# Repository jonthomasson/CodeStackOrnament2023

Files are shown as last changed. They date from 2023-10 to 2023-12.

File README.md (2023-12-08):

# CodeStack Team C 2023 Christmas Ornament Project

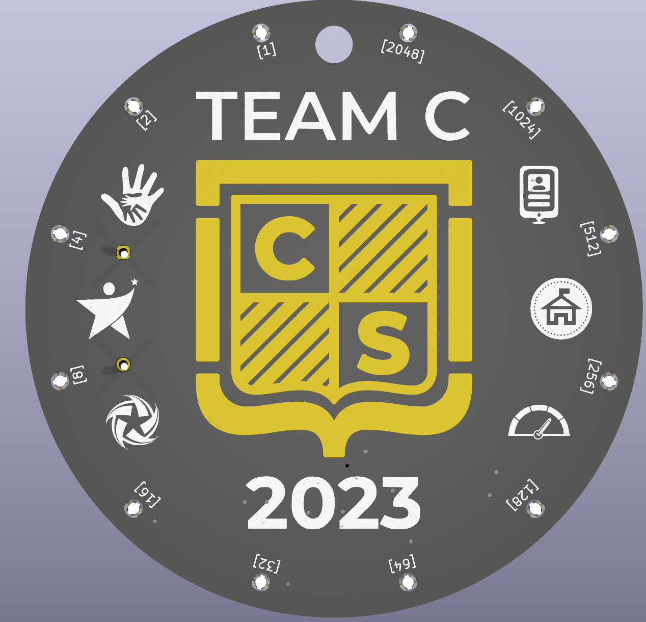
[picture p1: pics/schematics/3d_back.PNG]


## Overview

Welcome to the CodeStack Team C Christmas Ornament project! This isn't just any holiday decoration; it's a geeky masterpiece designed by developers for developers. Embodying the spirit of CodeStack, this unique ornament is a playful blend of electronics and a bit of geek culture, perfect for those who appreciate the quirks of digital logic and binary systems, which at its core are the systems which run our code!

### Circuit Description

Our circuit is centered around the 555 timer IC, configured in astable mode to generate a 4Hz timing signal, which feeds into a CD74HC4040 binary counter. The output from this binary counter powers 12 LEDs arranged around the PCB in a binary sequence.

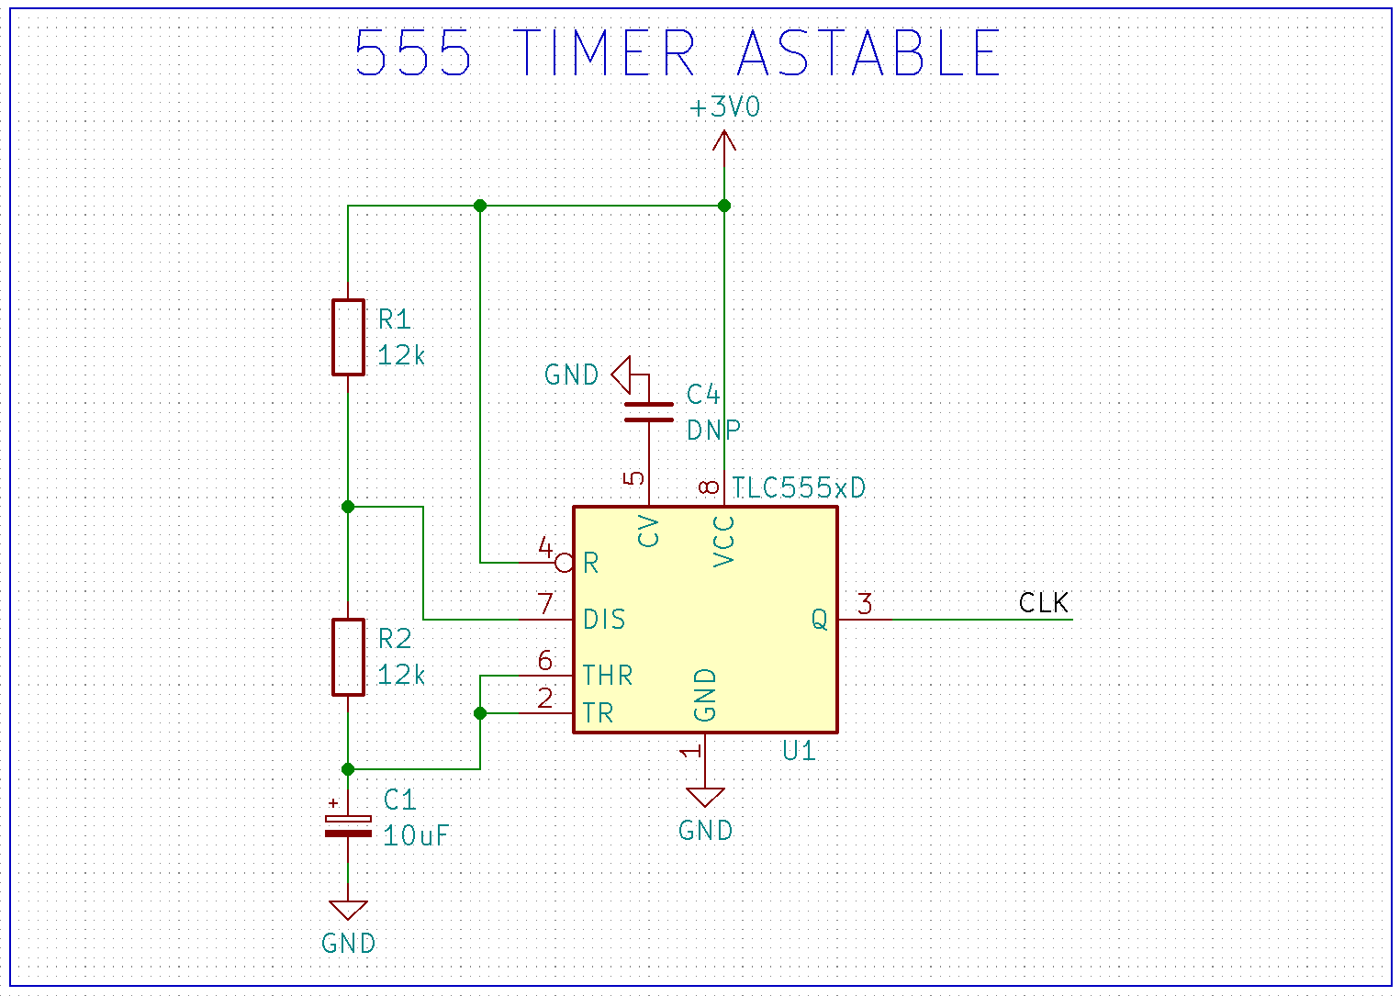
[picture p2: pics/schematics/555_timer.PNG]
555 Timer Schematic


#### Binary Counter and LED Display

At the core of our ornament is the CD74HC4040 binary counter. Unlike traditional LED displays, this counter follows a binary sequence, lighting up LEDs in a pattern that reflects binary counting principles.

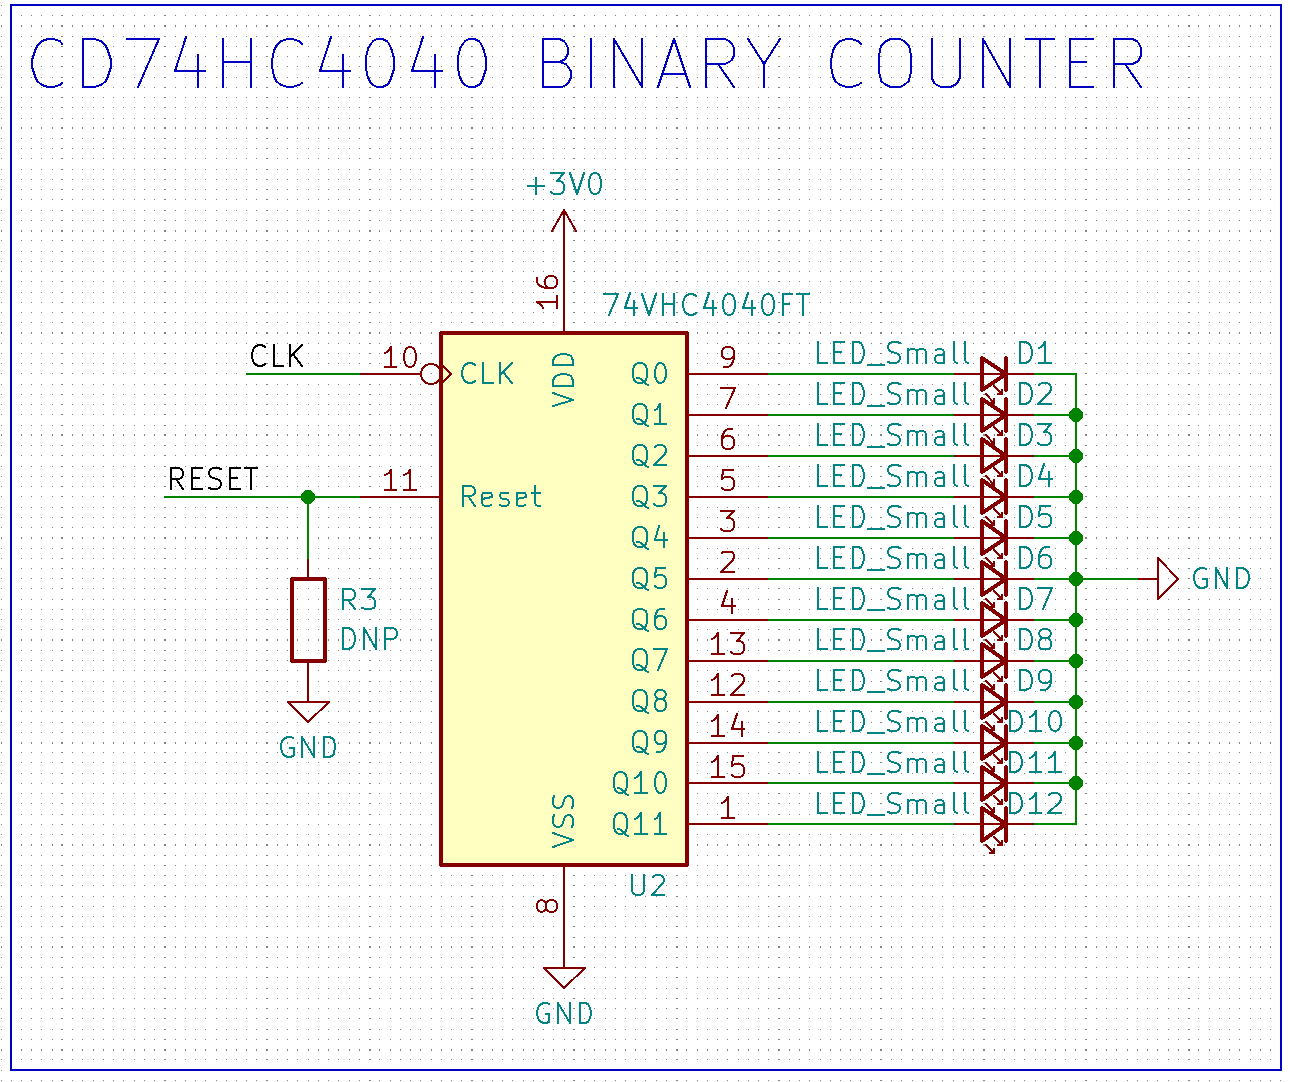
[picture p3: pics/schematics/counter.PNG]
Binary Counter Schematic


#### Reset Circuit

We've included a reset circuit using the TPS3840PH for a consistent experience. This setup ensures that the binary counter starts at zero every time the ornament is powered up. A manual reset button is also provided for added user control.

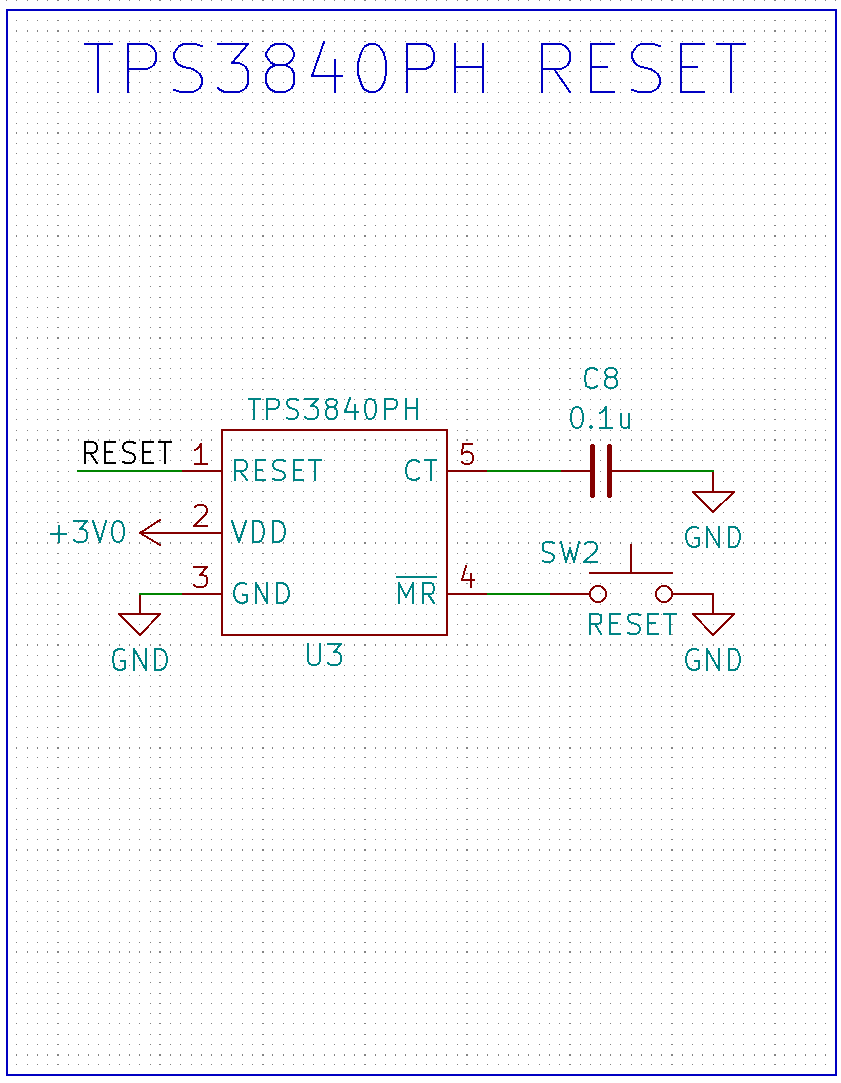
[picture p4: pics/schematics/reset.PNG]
Reset Circuit Schematic


## Embracing the Geekiness

This ornament is a nod to our geeky nature at CodeStack. It's designed to intrigue and amuse, combining fundamental electronics with a bit of developer humor. It's more than just a festive decoration; it's a representation of our love for coding, circuitry, and all things geeky.

## Binary Counting Explained

This ornament is a hands-on lesson in binary counting. The binary counter ranges from 0 to 4096, with each LED representing a binary power:

- 1, 2, 4, 8, 16, 32, 64, 128, 256, 512, 1024, and 2048.

As the counter advances, the corresponding LEDs light up. To find the current count, simply add the values of all illuminated LEDs. It's a delightful way to visualize how binary numbers work! Below is a representation of how the process of counting in binary works:

Binary Counting
## A Festive Joke

At first glance, it might just seem like an oddly blinking LED ornament. But in true CodeStack fashion, there's more than meets the eye. It's a playful demonstration of binary counting, making it not just a decoration, but a conversation piece about digital electronics and our geeky passions.

## Conclusion

Embrace your inner geek! This project aims to be a testament to our love for technology, coding, and a bit of festive fun. Enjoy this unique blend of holiday cheer and geek culture!

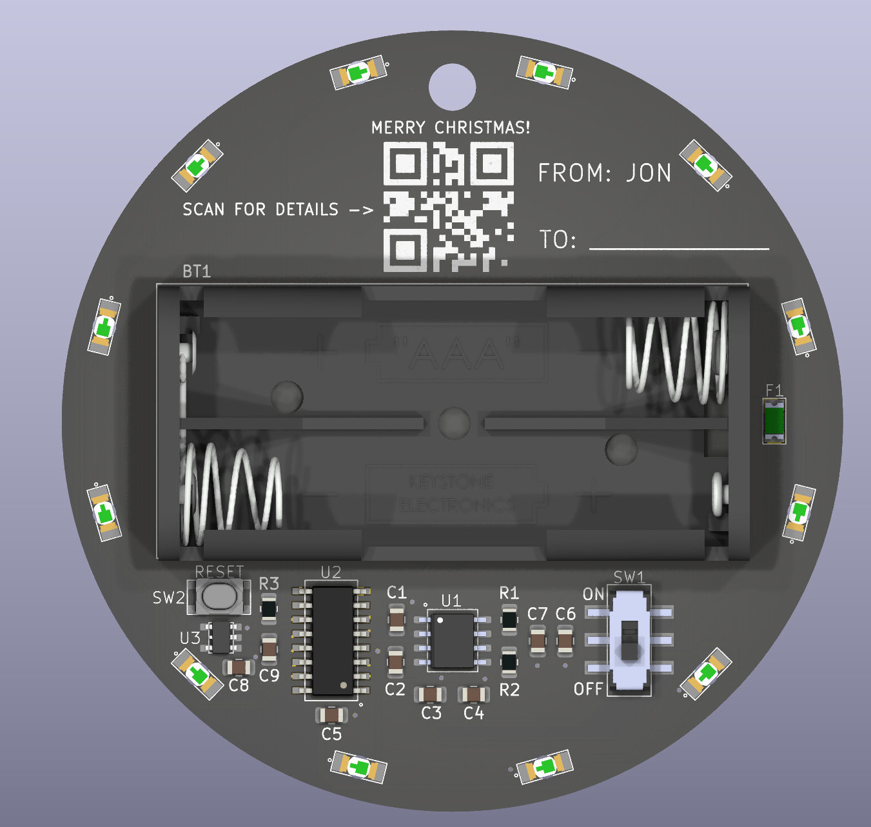
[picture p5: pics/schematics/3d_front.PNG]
Ornament Picture Front

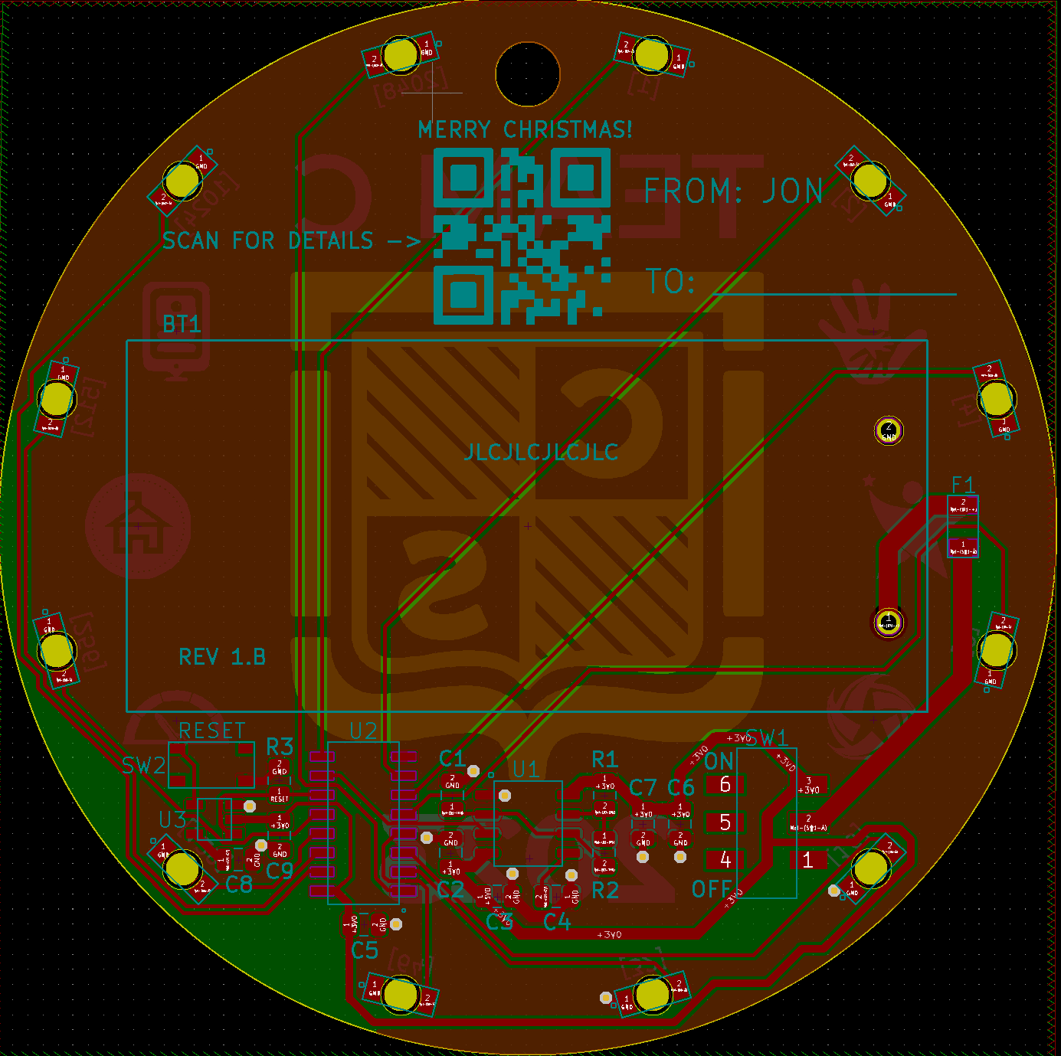
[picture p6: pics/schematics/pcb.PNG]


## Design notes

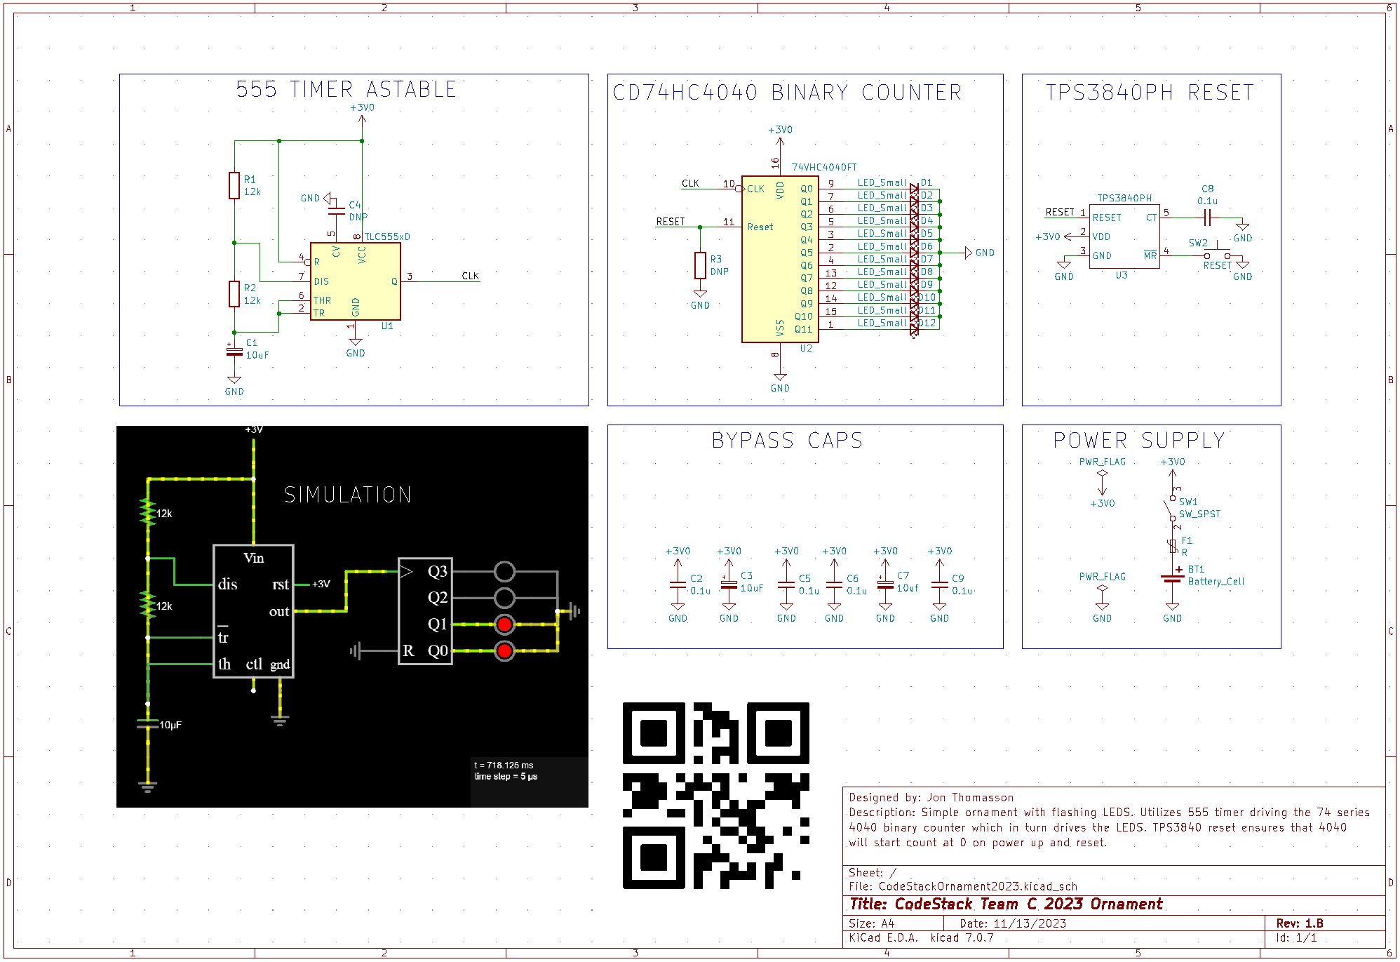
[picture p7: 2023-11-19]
pics/schematic.PNG

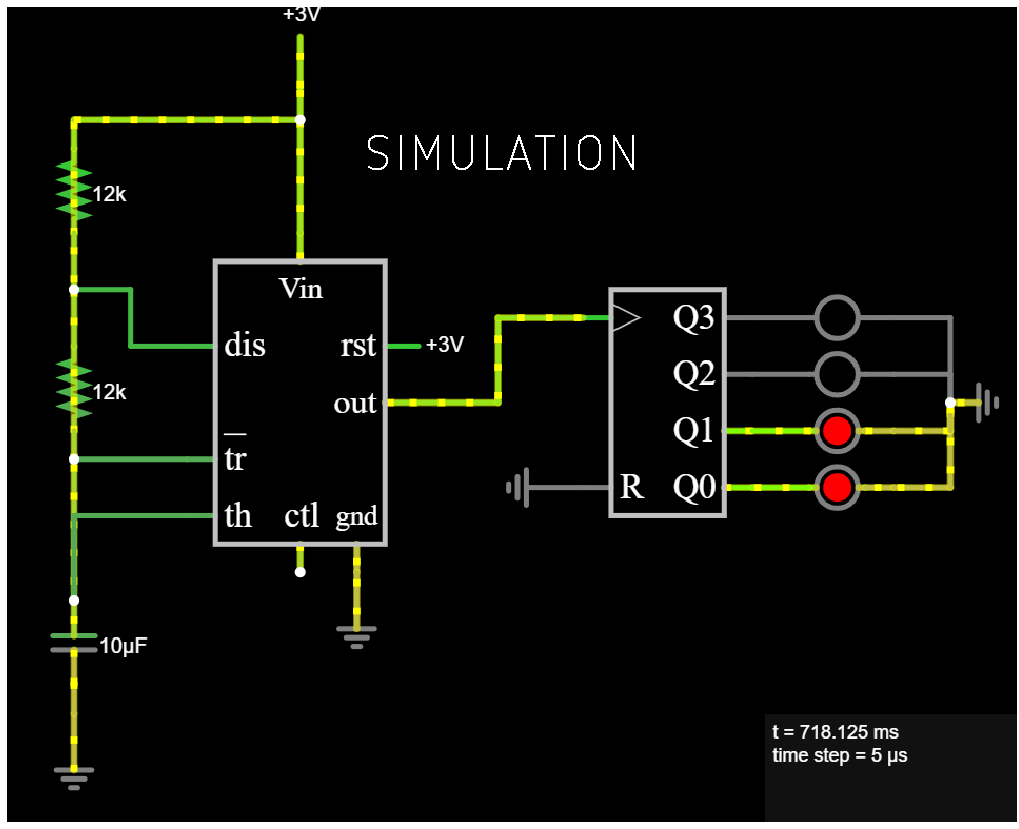
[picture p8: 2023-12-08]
pics/schematics/simulation.PNG

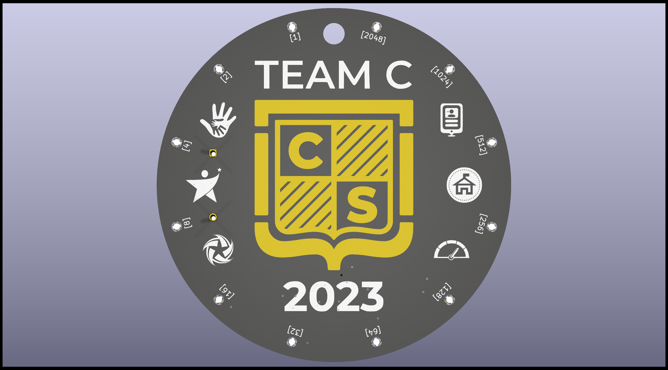
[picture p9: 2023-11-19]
pics/board-front-3d.png

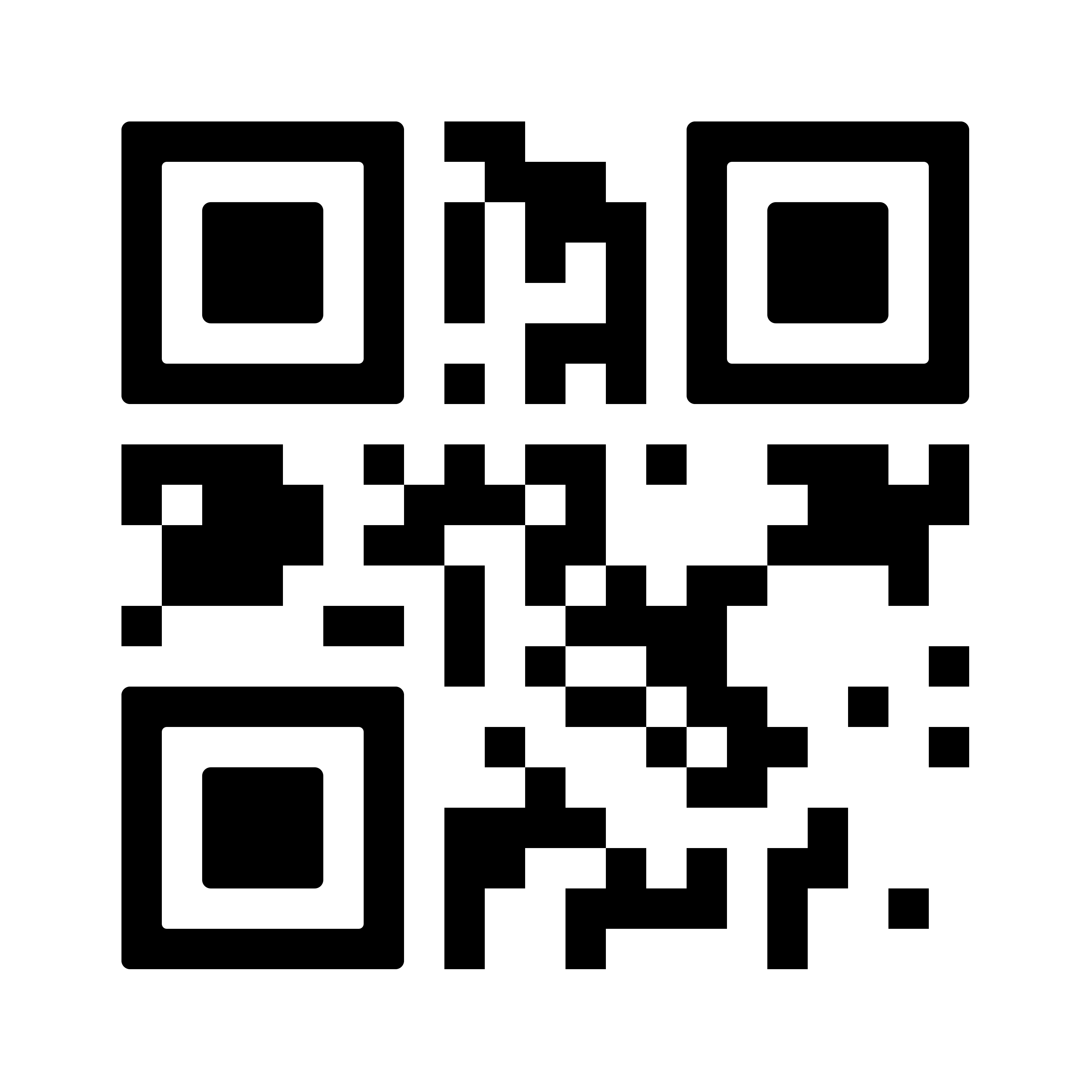
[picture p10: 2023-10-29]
pics/bit_ly_teamc_23.png

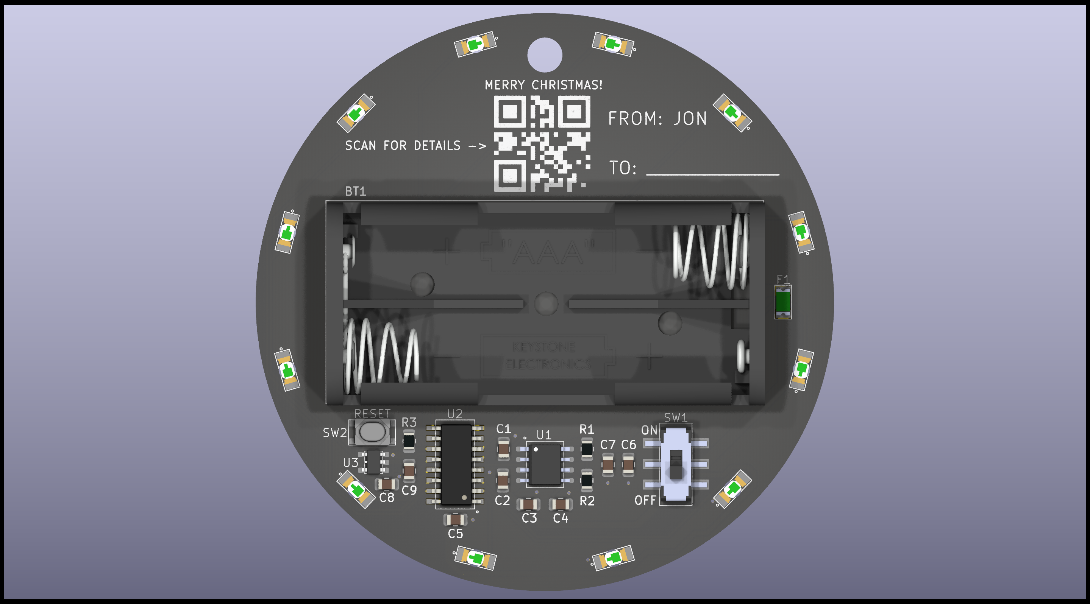
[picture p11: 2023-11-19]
pics/board-back-3d.png

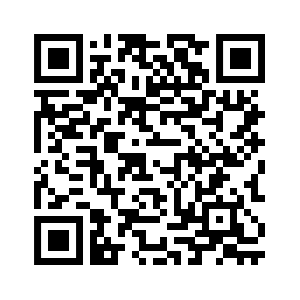
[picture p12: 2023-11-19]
pics/qr.png

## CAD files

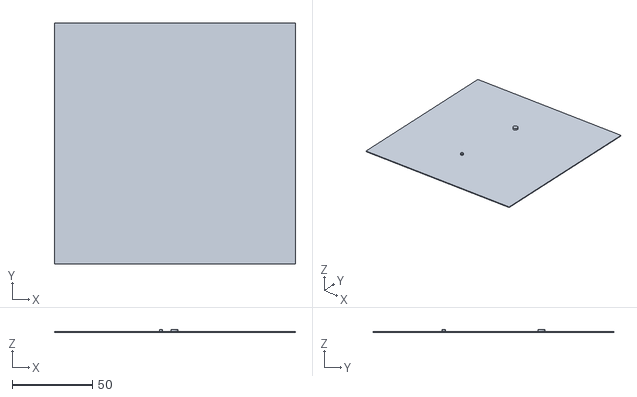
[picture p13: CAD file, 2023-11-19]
mech/team_c_2023_ornament_jig.stl
150.0 x 150.0 x 2.10

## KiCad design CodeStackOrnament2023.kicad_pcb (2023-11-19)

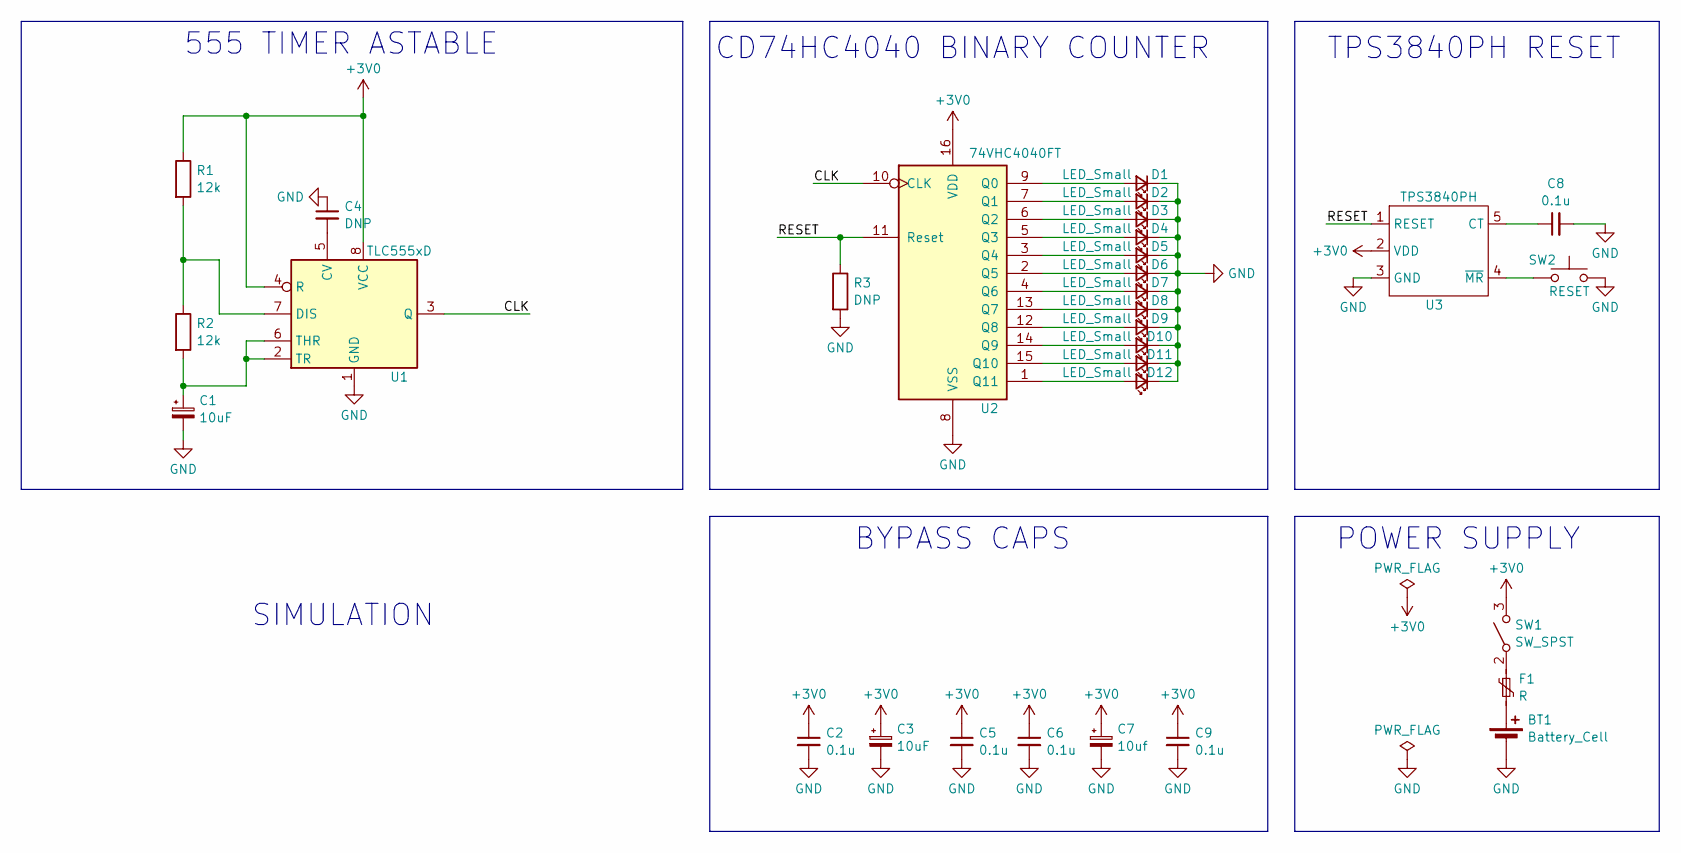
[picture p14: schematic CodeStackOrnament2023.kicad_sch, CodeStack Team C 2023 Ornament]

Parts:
BT1: Battery_Cell; BAT_2468
C1, C3: 10uF; C_0805_2012Metric
C2, C5, C6, C8, C9: 0.1u; C_0805_2012Metric
C4: DNP; C_0805_2012Metric
C7: 10uf; C_0805_2012Metric
D1, D2, D3, D4, D5, D6, D7, D8, D9, D10, D11, D12: LED_Small; 156120RS75300_LED
F1: R; SMD1206B050TF_FUSE
R1, R2: 12k; R_0805_2012Metric
R3: DNP; R_0805_2012Metric
SW1: SW_SPST; JS202011SCQN_SWITCH
SW2: RESET; PTS815_SWITCH
U1: TLC555xD; TLC555_SOIC
U2: 74VHC4040FT; CD74HC4040M96_SOIC16
U3: TPS3840PH; TPS3840_RESET

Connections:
+3V0: C2.1, C3.1, C5.1, C6.1, C7.1, C9.1, R1.1, SW1.3 (B), U1.4 (R), U1.8 (VCC), U2.16 (VDD), U3.2 (VDD)
/CLK: U1.3 (Q), U2.10 (CLK)
/RESET: R3.1, U2.11 (Reset), U3.1 (RESET)
GND: BT1.2 (-), C1.2, C2.2, C3.2, C4.1, C5.2, C6.2, C7.2, C8.2, C9.2, D1.1 (K), D2.1 (K), D3.1 (K), D4.1 (K), D5.1 (K), D6.1 (K), D7.1 (K), D8.1 (K), D9.1 (K), D10.1 (K), D11.1 (K), D12.1 (K), R3.2, SW2.4, U1.1 (GND), U2.8 (VSS), U3.3 (GND)
unnamed: BT1.1 (+), F1.2
unnamed: D1.2 (A), U2.9 (Q0)
unnamed: D2.2 (A), U2.7 (Q1)
unnamed: D3.2 (A), U2.6 (Q2)
unnamed: D4.2 (A), U2.5 (Q3)
unnamed: D5.2 (A), U2.3 (Q4)
unnamed: D6.2 (A), U2.2 (Q5)
unnamed: D7.2 (A), U2.4 (Q6)
unnamed: D8.2 (A), U2.13 (Q7)
unnamed: D9.2 (A), U2.12 (Q8)
unnamed: D10.2 (A), U2.14 (Q9)
unnamed: D11.2 (A), U2.15 (Q10)
unnamed: D12.2 (A), U2.1 (Q11)
unnamed: F1.1, SW1.2 (A)
unnamed: C4.2, U1.5 (CV)
unnamed: R1.2, R2.1, U1.7 (DIS)
unnamed: C1.1, R2.2, U1.2 (TR), U1.6 (THR)
unnamed: C8.1, U3.5 (CT)
unnamed: SW2.1, U3.4 (~MR)

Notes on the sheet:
BYPASS CAPS
TPS3840PH RESET
SIMULATION
POWER SUPPLY
CD74HC4040 BINARY COUNTER
555 TIMER ASTABLE

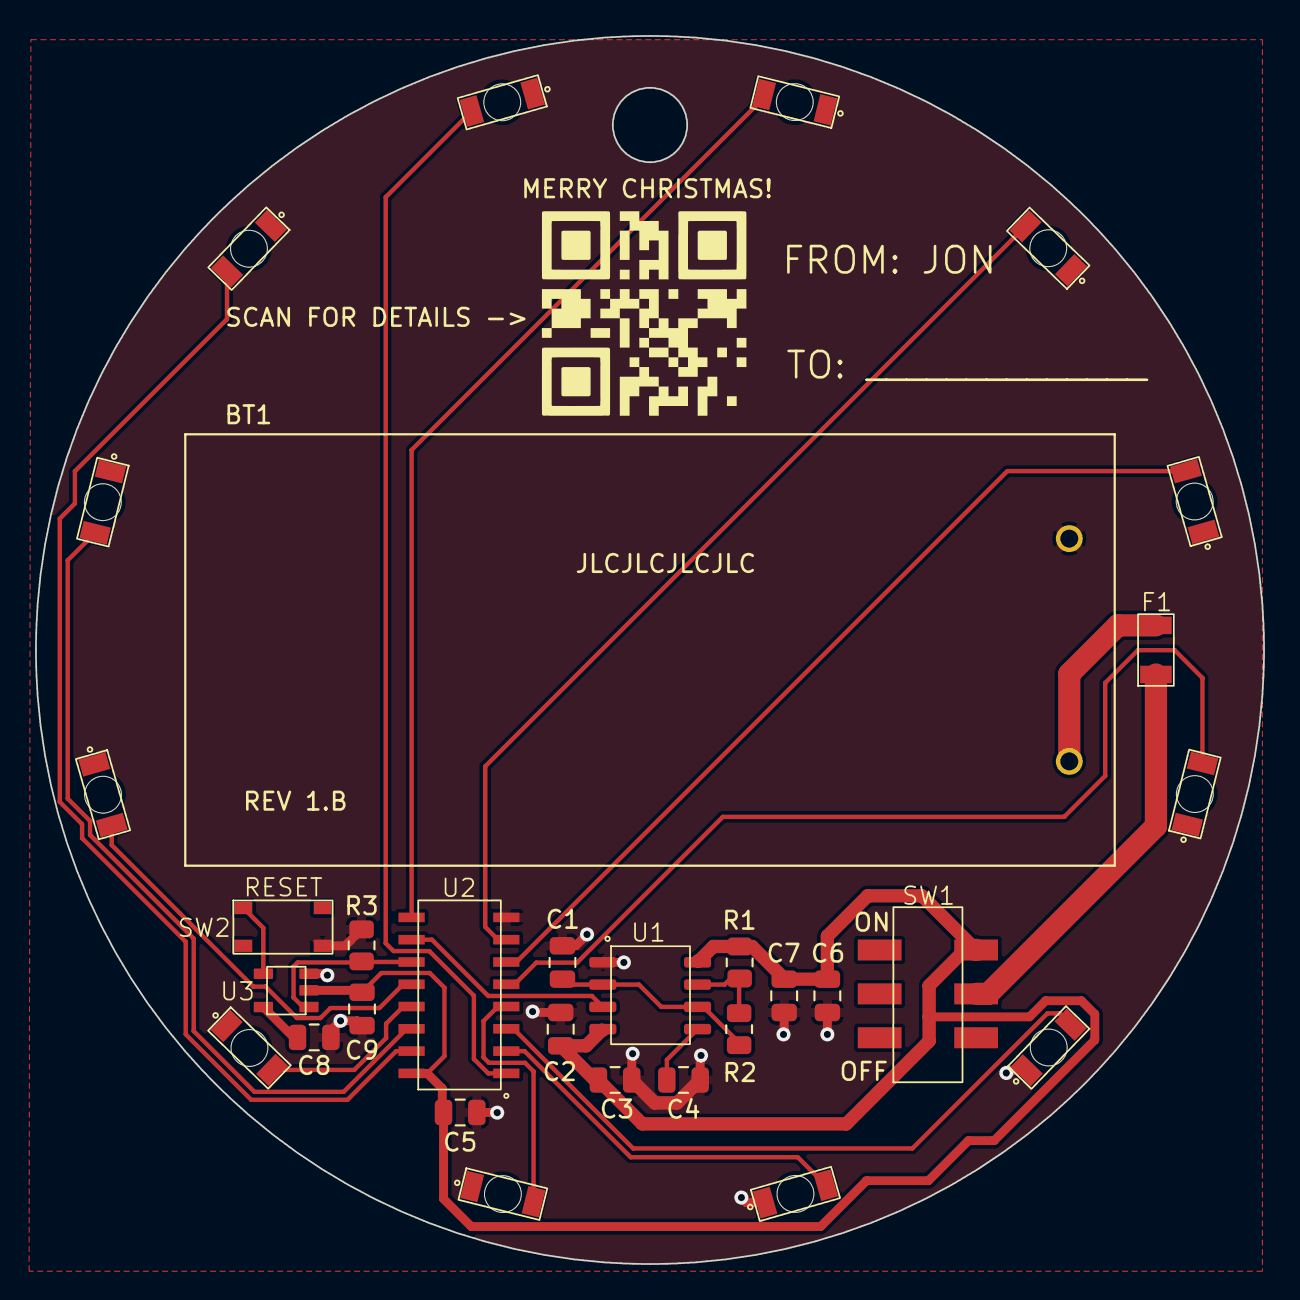
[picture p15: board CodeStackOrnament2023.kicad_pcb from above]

Board: 2 copper layers, 70.0 x 70.0 mm, 31 parts (0 on the bottom side), 23 nets.

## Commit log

2023-10-12 initial checkin
    [CodeStackOrnament2023.kicad_pcb, CodeStackOrnament2023.kicad_sch]
2023-10-13 adding battery and boost circuit
    [CodeStackOrnament2023.kicad_sch]
2023-10-16 finishing schematic. starting on footprints.
    [CodeStackOrnament2023.kicad_sch]
2023-10-17 adding switch footprint and model
2023-10-18 adding footprint for battery holder
    [CodeStackOrnament2023.kicad_sch]
2023-10-20 refactoring power
    [CodeStackOrnament2023.kicad_sch]
2023-10-22 spice and footprint models. refactoring power supply.
    [CodeStackOrnament2023.kicad_pcb, CodeStackOrnament2023.kicad_sch]
2023-10-23 starting board design
    [CodeStackOrnament2023.kicad_pcb, CodeStackOrnament2023.kicad_sch]
2023-10-24 updating footprints
    [CodeStackOrnament2023.kicad_pcb]
2023-10-24 board layout
    [CodeStackOrnament2023.kicad_pcb, CodeStackOrnament2023.kicad_sch]
2023-10-24 starting board routing
    [CodeStackOrnament2023.kicad_pcb, CodeStackOrnament2023.kicad_sch]
2023-10-25 more routing
    [CodeStackOrnament2023.kicad_pcb, CodeStackOrnament2023.kicad_sch]
2023-10-25 more routing and layout
    [CodeStackOrnament2023.kicad_pcb]
2023-10-25 Finishing routing.
    [CodeStackOrnament2023.kicad_pcb]
2023-10-26 increasing board size a bit.
    [CodeStackOrnament2023.kicad_pcb]
2023-10-28 adding codestack solder mask logo
    [CodeStackOrnament2023.kicad_pcb]
2023-10-28 updating silkscreen
    [CodeStackOrnament2023.kicad_pcb]
2023-10-28 adjusting codestack logo on solder mask
    [CodeStackOrnament2023.kicad_pcb]
2023-10-29 silkscreen logos
    [CodeStackOrnament2023.kicad_pcb]
2023-10-29 adding qr code and a few more logos for silkscreen.
    [CodeStackOrnament2023.kicad_pcb]
2023-10-30 fixing drc
    [CodeStackOrnament2023.kicad_pcb]
2023-10-30 fixing last drc
    [CodeStackOrnament2023.kicad_pcb]
2023-10-30 aligning silkscreen
    [CodeStackOrnament2023.kicad_pcb]
2023-10-30 more alignment with u2
    [CodeStackOrnament2023.kicad_pcb]
2023-10-31 adding gerbers
    [CodeStackOrnament2023-B_Cu.gbr, CodeStackOrnament2023-B_Mask.gbr, CodeStackOrnament2023-B_Paste.gbr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]
2023-11-05 adding gerbers. cleaning up schematic.
    [CodeStackOrnament2023.kicad_pcb, CodeStackOrnament2023.kicad_sch]
2023-11-11 starting rev 1.b with added reset circuitry.
    [CodeStackOrnament2023.kicad_sch]
2023-11-11 rev 1.b adding footprints
    [CodeStackOrnament2023.kicad_sch]
2023-11-12 finshed routing rev 1.b with reset circuit
    [CodeStackOrnament2023.kicad_pcb, CodeStackOrnament2023.kicad_sch]
2023-11-19 rev 1.b added a reset circuit to ensure counter starts at 0. Reorganizing schematic.
    [CodeStackOrnament2023-B_Cu.gbr, CodeStackOrnament2023-B_Mask.gbr, CodeStackOrnament2023-B_Paste.gbr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]
2023-12-08 adding pics of finished board and schematic
    adding pics of finished board and schematic.
